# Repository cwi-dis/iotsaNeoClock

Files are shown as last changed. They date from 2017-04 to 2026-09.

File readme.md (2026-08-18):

# iotsaNeoClock - an internet-connected clock




A clock comprised of 60 NeoPixel LEDs. Shows the time, but can also show programmable patterns (as alerts) and temporal information (such as expected rainfall for the coming hour). Schematics and building instructions included.

Home page is <https://github.com/cwi-dis/iotsaNeoClock>.
This software is licensed under the [MIT license](LICENSE.txt) by the   CWI DIS group, <http://www.dis.cwi.nl>.

## Software requirements

* Arduino IDE, v1.6 or later.
* The iotsa framework, download from <https://github.com/cwi-dis/iotsa>.
* The new LiquidCrystal library, download from <https://bitbucket.org/fmalpartida/new-liquidcrystal>.
* The [Adafruit NeoPixel library](https://github.com/adafruit/Adafruit_NeoPixel).

## Hardware requirements

* a iotsa board (or another esp8266-based board).
* A strip of 60 NeoPixels.
* Optionally an LDR to auto-adjust the clock brightness.

## Hardware construction

Construction of the iotsa board is very simple: the NeoPixel strip _data in_ should be connected to _GPIO 14_ and _power_ and _ground_ should be connected to _5V_ and _GND_, respectively.

If you want light adaptation you also connect an LDR (light dependent resistor) between _AIN_ and _3V3_ and a resistor of around 10Kohm between _AIN_ and _GND_.

At this point you can test that things work (but you have to mentally group your 60 NeoPixels into 12 groups of 5, with the very first LED being at the top of the clock, and the last LED being the innermost at the 11 o'clock position).

Now you need to cut your NeoPixels into 12 groups of 5, and somehow affix them to a frame. There is a template in [extras/pixel-layout.pdf](extras/pixel-layout.pdf) to help you get things spaced correctly. The _data in_ of the 12 o'clock 5-pixel strip goes to the iotsa board. The _data out_ of the 12 o'clock 5 pixel strip goes to the _data in_ of the 1 o'clock 5 pixel strip. And so forth. The _data out_ of the 11 o'clock strip is not connected. All the _power_ are connected together (and to _5V_) and all the _ground_ are connected together (and to _GND_), how you do this does not matter. You probably want to tape or glue your wires to the template.

I bought a 5 euro clock with a glass front, ripped all the internals out and glued the NeoPixels to the template, then glued the template to what was left of the clock. Finally I put semi-opaque paper on the inside of the glass and put the clock together again.

If you have the LDR you want to somehow position it so that it catches the incident light on the clock (but not the light from the clock), and that it is not too ugly.

## Building the software

You need to define (or `#undef`) `WITH_BRIGHTNESS` depending on whether you want to be able to change the clock brightness over the net (and definitely if you have the LDR for auto-brightness).

If you want different colors for the hands your can adapt the `COLOR_SEC`, `COLOR_MIN` and `COLOR_HOUR` defines (in `iotsaNeoClockMod.h`). If you want different patterns to show the time you need to modify `IotsaNeoClockMod::updateClockFace()` in `iotsaNeoClockMod.cpp`.

## Operation

The first time the board boots it creates a Wifi network with a name similar to _config-iotsa1234_.  Connect a device to that network and visit <http://192.168.4.1>. Configure your device name (using the name _neoclock_ is suggested), WiFi name and password, and after reboot the iotsa board should connect to your network and be visible as <http://neoclock.local>.

### Configuration

Visit <http://neoclock.local/ntpconfig> to configure the NTP (Network Time Protocol) server to use (but the default _pool.ntp.org_ will usually work) and your timezone. After about half a minute the clock should have a fix and start displaying the right time. The time is also shown on the ntpconfig page and on the clock homepage.

You can change the brightness of the clock at <http://neoclock.local/brightness> (or, as JSON, at <http://neoclock.local/api/brightness>). You can either set a single brightness value, or set _Adapt to ambient light_ and set a minimum and maximum brightness.

You can set the LED rotation offset (the clock position where LED 0 actually sits -- needed on the first two clocks built, which have LED 0 at the 1 o'clock position) at <http://neoclock.local/neoclock> (or, as JSON, at <http://neoclock.local/api/neoclock>).

### Alerts

The clock can display alerts, which are sequences of patterns, there are sample patterns in [data/data](data/data).
Each line consists of 181 numbers: a duration (in milliseconds) and 60 R, G and B values for each of the pixels. Triggering an alert will simply show the lines in order.

Alerts share the device's generic `/upload` file store with arbitrary other files, so alert pattern files must be named `alert-<name>`, e.g. `alert-Red`. Upload via <http://neoclock.local/upload>, see what's available at <http://neoclock.local/alert> (or, as JSON, at <http://neoclock.local/api/neoclock>, which also reports the currently-playing alert, if any), then trigger with the name *without* the `alert-` prefix, e.g. <http://neoclock.local/alert?alert=Red>. Stop a running alert early with <http://neoclock.local/alert?stop=1>. The same trigger/stop can be done as JSON: `PUT /api/neoclock {"alert": "Red"}` / `{"alert": ""}`.

Alerts are intended to be shown programmatically when something interesting has happened, such as a doorbell being pushed, or a facebook mention, or whatever you can think of. [Igor](https://github.com/cwi-dis/iotsa) is a good way of connecting triggers to alerts.

### Status indicators

The clock can also display _status information_, which is intended to be longer-lived. Think of things like "the garden door is open" or "the temperature in the freezer is above -20 C". There are two types of status indicators, each with its own URL:

* <http://neoclock.local/status> -- the inner ring, used for _main status information_. All 12 LEDs show the same color and intensity.
* <http://neoclock.local/temporal> -- the outer ring, used for _temporal status information_, information for the coming hour. The LEDs all have the same color, but the intensity can vary. This can be used to get a quick visual indication of things like the expected rainfall in the coming hour.

Some example URLs to trigger status indicators:

```
http://neoclock.local/status?color=0x00ff00
```

Sets the inner ring to bright green.

```
http://neoclock.local/status?color=0x006600&timeout=60
```
Sets the inner ring to medium green for 60 seconds, then revert to normal.

```
http://neoclock.local/status?color=0&nextColor=0xff0000&timeout=300
```
Sets the inner ring to normal (unlit) for 5 minutes, then go to a very bright red. This can be used as a watchdog: by re-issuing this command within those 5 minutes the red will never show up. Unless the agent that is responsible for contacting the URL is too late.

```
http://neoclock.local/temporal?color=0xccffff&factors=1.0,0.0,0.0,0.5&timeout=300
```
Sets the outer ring with timed information. Where the minute hand is pointing is set to 100% lightish blue, 15 minutes into the future to that color with 50% intensity. After 5 minutes the outer ring will revert to normal.

### Automatic rain forecast (buienradar.nl)

Some NeoClocks have a built-in rain forecast feature: they periodically fetch the precipitation forecast for a configured location from [buienradar.nl](https://www.buienradar.nl) (Netherlands only) and use it to drive the outer ring automatically -- no external process needed to push `/temporal` updates.

If your clock has this feature, configure it at <http://neoclock.local/buienradar> (or, as JSON, at <http://neoclock.local/api/buienradar>): fill in your latitude and longitude -- the easiest way to find them is to right-click your location on Google Maps and copy the two numbers shown from the top of the menu that pops up (not "Copy link", which gives you something else entirely) -- and the outer ring will start showing the forecast for the coming hour automatically. There's also an _Enabled_ switch on that page, in case you ever want to turn the feature off.

If your clock doesn't have this feature, you can still get the same effect yourself: have some external process fetch a forecast periodically and push it to `/temporal`, as shown above.

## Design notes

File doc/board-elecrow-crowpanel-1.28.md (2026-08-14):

# Hardware reference: Elecrow CrowPanel ESP32 1.28" round display

Reference notes for the board being investigated for #4 ("multiple renderers"). Compiled from:

- The vendor's public repo, [Elecrow-RD/CrowPanel--ESP32-Display-1.28-R-inch-240240](https://github.com/Elecrow-RD/CrowPanel--ESP32-Display-1.28-R-inch-240240) (factory firmware source, other example sketches, Eagle schematic `CrowPanel ESP32 Display 1.28(R) Inch_V1.0_240507.sch`).
- Direct queries against a physical unit (`iotsa dfu info`, `espefuse summary`, USB descriptor inspection).

Confidence varies by item — noted per section. Where a claim comes only from the vendor's source/schematic and hasn't been independently exercised, it's marked accordingly.

**Board variants:** the single Eagle schematic appears to cover more than one Elecrow SKU sharing the same PCB, with some parts populated only on certain variants. Confirmed so far: the "extra flash" footprint (`U4`, below) really is silkscreened `U4` on the physical unit, matching the schematic — but that unit doesn't actually have it populated. Separately, this specific unit (the round-clock demo one) doesn't appear to have the rotary encoder populated or used either; Jack has a second variant of this board with a physical pushbutton + rotary encoder that most likely does populate and use it — and quite possibly `U4` too. Treat the encoder section below as "what the shared schematic supports," not as confirmed-present on this particular unit.

## MCU

- **ESP32-C3FH4** (schematic ref `U3`): single-core RISC-V @ 160MHz, 4MB flash embedded in-package (vendor `XMC`), WiFi + BT5 LE.
- Confirmed on the physical unit via `iotsa dfu info` / `espefuse summary`: silicon revision v0.4, 40MHz crystal, MAC `94:a9:90:54:e6:70`.
- Shipped with secure boot off, flash encryption off, no eFuse keys burned, download mode not locked out — open for reflashing.

## Power

- USB-C connector (`J1`, 16-pin) for power and programming.
- `RT9013-30PB` (`U6`): 5V → 3.3V LDO.
- `TP4054` (`U2`, DFN8): single-cell Li-ion/LiPo linear charger, with a `CHRG` status output.
- `B3`, a 1.0mm-pitch 4-pin battery connector (`BAT-1.0MM-W`) — only 2 of the 4 pins are used (`B+`/`B-`); the other two are tied straight to GND. This is almost certainly the 2-pin-looking JST-style connector you spotted — confirms the board is designed to take a LiPo cell and charge it over USB.
- Separately, a **CR927 coin-cell holder** (`B2`) diode-ORed (`D5`, dual-diode) onto the RTC's own supply rail (`VDD_RTC`) — an independent backup power source just for the BM8563 RTC chip and its 32.768kHz crystal, so timekeeping survives even with both USB and the main LiPo disconnected. Don't confuse this with the main LiPo connector — different purpose, different battery.

## Display + touch (round LCD module)

The GC9A01-driven 240×240 round IPS panel and its capacitive touch controller live on their own FPC module, connected to the mainboard via connector `J2`. Not independently verified — this is what the vendor's LovyanGFX init code claims, and the display visibly works, but the pin wiring itself hasn't been cross-checked any other way:

- SPI: `sclk`=GPIO6, `mosi`=GPIO7, `dc`=GPIO2, `cs`=GPIO10 (no `miso`, no dedicated hardware reset pin).
- Touch (CST816D): I2C, shared bus (`SDA`=GPIO4, `SCL`=GPIO5), `INT`=GPIO0. Never exercised in our testing (no touch events observed).
- Both **LCD reset** and **touch reset** are *not* direct GPIOs — both are routed through the IO expander (below). Same for **backlight enable**.

## IO expander — PI4IOE5V6408ZTAEX (`U1`)

I2C, address pin tied to GND (fixed address). This one chip fans out to several things that look at first glance like they'd be direct GPIOs:

| Expander pin | Net name | Drives |
|---|---|---|
| P0 | `MOTOR_P0` | Vibration motor (via transistor `Q3`) |
| P2 | `LED_P2` | LCD backlight enable (via MOSFET `Q1`, pulls `LEDK` low) |
| P3 | `TP_RESET` | Touch controller reset |
| P4 | `LCD_RESET` | LCD reset |
| P1, P5–P7 | — | Unused — factory firmware only configures P0–P4 as outputs |

The expander's `INT` pin exists on the chip but **is not wired to any ESP32-C3 GPIO** in this design — despite the schematic net being labeled `PI4-INT_IO3`, which looks like a GPIO3 reference but isn't connected to the MCU at all (verified from the net's wire list — it only touches the expander's own INT pin). The real GPIO3 net is separately named `BEEP_IO3` (see Buzzer, below) — an unfortunate naming collision in the schematic, not an actual shared pin. Practical upshot: expander state has to be polled over I2C, there's no interrupt-driven path.

This matches the factory firmware's own `set_pin_io()` calls in `setup()` exactly: pin 3 (`TP_RESET`) and pin 4 (`LCD_RESET`) are driven high first, and pin 2 (`LED_P2`, backlight) only after LVGL has finished initializing — avoids flashing garbage on screen before the UI is ready.

## RTC — BM8563EMA (`U7`)

I2C, shared bus, fixed address. 32.768kHz crystal (`Y1`). Backed up independently by the CR927 coin cell described above. Confirmed working — the factory firmware reads it once a minute and we saw the expected serial output.

## Rotary encoder + buttons

- Rotary encoder, part `E5A5-23-12-8` (`U5`): A=GPIO19, B=GPIO18, integrated pushbutton=GPIO8 (`ENCODER_A_PIN`/`ENCODER_B_PIN`/`SWITCH_PIN` in the factory source). Not independently exercised, and per Jack's physical inspection, likely **not populated on this particular unit** — see "Board variants" above. Probably populated and used on the sibling pushbutton+encoder variant instead.
- RESET (`K1`) and BOOT/download (`K2`, GPIO9) buttons — the standard pair for manual bootloader entry, though on this board it's normally unnecessary since the USB bridge chip auto-resets into the bootloader (see below).
- A third, side-mounted "custom" button (`K3`) → GPIO1 (`Custom_PIN`). Confirmed directly wired (not through the expander) from both the factory source and the standalone `Button.ino` vendor example.

## Buzzer

Passive piezo buzzer (`BP1`, part `BEEP_7525`), driven through transistor `Q2`, directly on GPIO3 (`tone()` in the factory firmware). Never triggered in our testing (alarm never fired).

## USB/serial bridge

`CH340X`/`CH340E` (`U9`) — an external WCH USB-to-UART bridge chip, **not** the ESP32-C3's own native USB-Serial-JTAG peripheral. RXD/TXD go to GPIO20/21; DTR/RTS are wired to RESET and BOOT(GPIO9) for automatic bootloader entry (no manual button-holding needed for `iotsa dfu`/`esptool`/`pio upload`).

Independently confirmed from the host side: macOS enumerates the connected device as USB VID `0x1A86` (WCH) — matches the schematic exactly.

**Build-flag consequence:** because this is an external UART bridge and not native USB-CDC, firmware for this board should *not* need `ARDUINO_USB_MODE`/`ARDUINO_USB_CDC_ON_BOOT`-style flags the way a native-USB ESP32-C3/S3 board would — `Serial` here is a plain UART, same as any classic Arduino board.

## Extra flash footprint — confirmed: `U4`, unpopulated on this unit

The schematic includes a **second, discrete 8MB SPI NOR flash chip**, `W25Q64JVXGIQ` (`U4`) — completely separate from the ESP32-C3's own embedded 4MB. It's fully wired in the schematic (all of `DO`/`DI`/`CLK`/`CS`/`WP`/`HOLD` connect to real nets), so this isn't a stub or a leftover — it's a real, designed-in part on an 8-pin package footprint.

No SRAM or PSRAM part appears anywhere in the design, so it was never a SRAM/PSRAM candidate. **Confirmed by physical inspection:** the unpopulated 2×4-pad footprint is silkscreened `U4`, matching this part exactly. Not populated on this unit — per the "Board variants" note above, likely populated on the sibling pushbutton+encoder variant instead, alongside the encoder.

One caveat that still applies even now it's confirmed unpopulated here: this wouldn't show up either way in `iotsa dfu info`'s flash-size report. That only detects the chip's *boot* flash (the embedded 4MB) via the standard bootloader flash-probe protocol — it has no visibility into a second chip sitting on what would be a separate, general-purpose SPI bus.

## Partition table (as shipped)

Read directly off the physical unit via `iotsa dfu info` — not present anywhere in the vendor's repo (no `partitions.csv` committed; this was purely an Arduino IDE build-time choice):

```
nvs        0x9000    0x5000   (20KB)
otadata    0xe000    0x2000   (8KB)
app0       0x10000   0x3c0000 (~3.75MB, single ota_0 slot — no ota_1)
spiffs     0x3d0000  0x20000  (128KB, littlefs)
coredump   0x3f0000  0x10000  (64KB)
```

Single OTA slot only — the factory firmware can be updated in place, but there's no second slot for A/B rollback the way `iotsa`'s own OTA mechanism expects. Whatever partition scheme we pick for an iotsa-based build on this board will need real `ota_0`+`ota_1` slots, and given how much of the 4MB the factory image already claims, actual binary size should be measured early rather than assumed to fit.

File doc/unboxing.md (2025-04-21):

# NeoClock Manual

## Unpacking and connecting

Insert the power supply (5 volt, tip positive) into the little board at the back of the clock and connect to a power outlet.

The clock should show short green hour hand, a long yellow minute hand, a moving white second indicator and a yellow or pink ring.

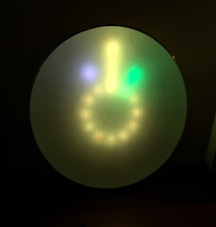
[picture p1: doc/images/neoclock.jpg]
Image of new NeoClock
> 

## Connecting to your WiFi

With the yellow or pink ring the NeoClock tells you that it does not know your WiFi. It will create its own WiFi network, with a name like _config-neoclock_ or _config-iotsa12345_ or something similar.

Connect to that WiFi network with a telephone, laptop or computer.

Open _Safari_ or _Chrome_ or another browser, and in the address bar type

```
http://192.168.4.1
```

This should show you the following window:

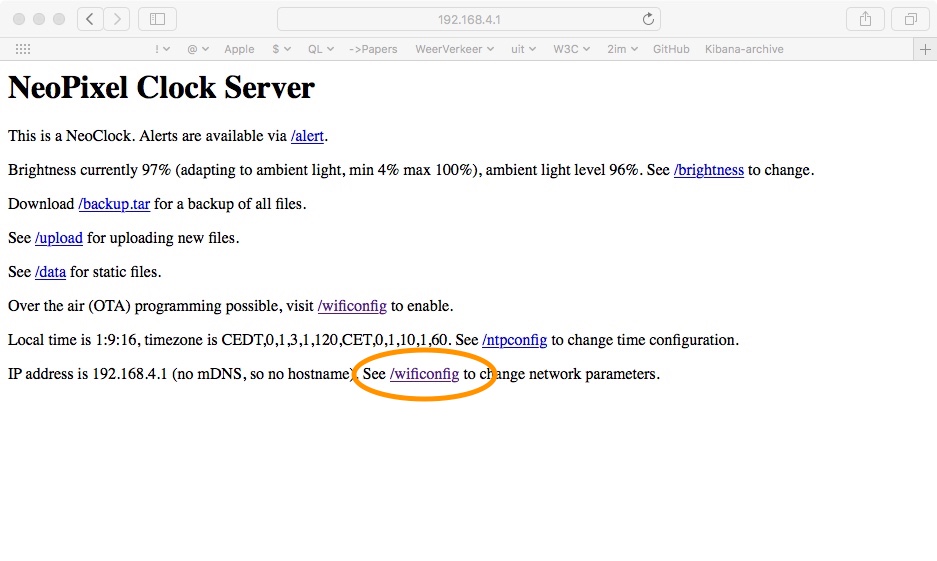
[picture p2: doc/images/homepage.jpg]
neoclock homepage screenshot
> 

Click the _/wificonfig_ link to go to the page where you can tell the NeoClock about your WiFi network:

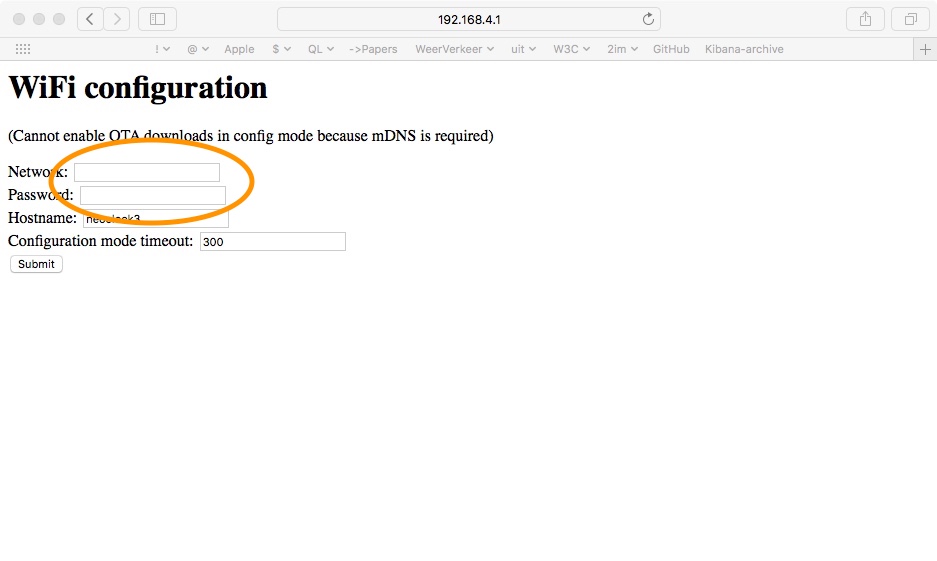
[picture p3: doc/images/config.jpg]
neoclock wificonfig screenshot
> 

Fill in the _Network_ and _Password_ fields with your WiFi name and WiFi password. 

Remember the name of your NeoClock, in the _Hostname_ field. (In this example it is _neoclock3_).

If you really want you can also give your clock a different name, but use only letters, digits and hyphen, no spaces or other characters. 

Press _Submit_.

The NeoClock will restart, and after a while should start showing a time (possibly wrong, because it does not know yet which timezone you are in), without the yellow center ring.

Connect your telephone (laptop, PC) back to your normal WiFi network.

## Configuring timezone

When both the NeoClock and your phone (laptop, computer) are connected to your WiFi network you can set it to the correct timezone by opening a browser and typing the following URL in the address bar (with the example _neoclock3_ replaced by the name you remembered above):

```
http://neoclock3.local
```

This will show you the _NeoPixel Clock Server_ page from above again. This time, select the _/ntpconfig_ link to bring you to the time configuration page:

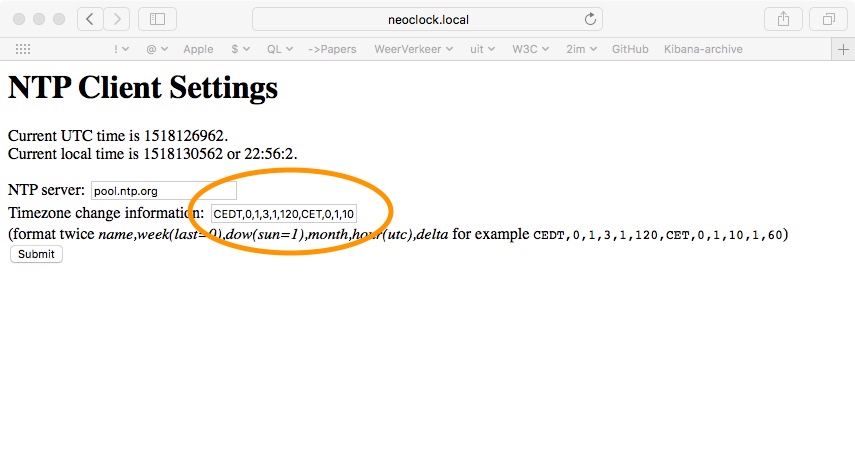
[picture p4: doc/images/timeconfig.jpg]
neoclock time config screenshot
> 

The format of the _Timezone change information_ configuration is rather complicated, but for continental Europe you can simply copy the example text 

```
CEDT,0,1,3,1,120,CET,0,1,10,1,60
```

and press _Submit_. 

> The format for the timezone string is called "posix TZ database". You can try looking up your location in <https://github.com/nayarsystems/posix_tz_db/blob/master/zones.csv>.

Your clock should now show the correct time.

## Clock brightness

You can change the brightness of the clock, and you can make it adapt to available light (so it does not blind you at night but you can still see it during the day).

> Note that adapting the brightness only works if your NeoClock has a little light sensor, probably somewhere near the top. Otherwise you can still set a brightness but it will not change.

Visit the clock homepage, and select the _/brightness_ page:

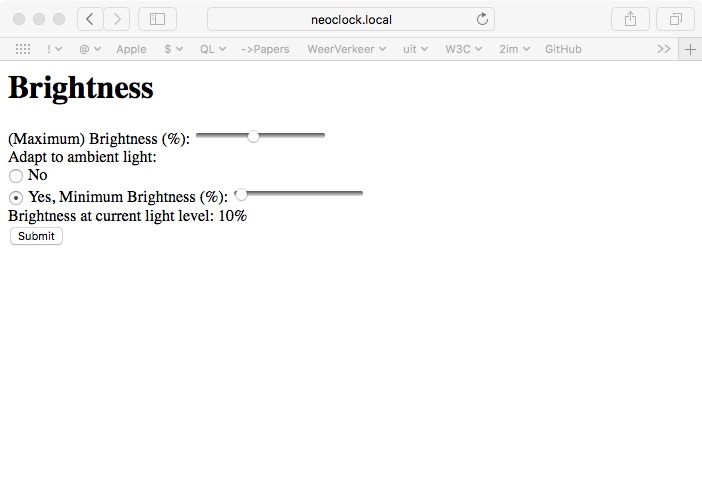
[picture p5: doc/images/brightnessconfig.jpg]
neoclock brightness config page
> 

Use the sliders to select maximum and minimum brightness, and select _Yes_ for adaptation. Press _Submit_.

You can test the brightness by covering the light sensor with something (or shining a light at it).

## More

Your NeoClock can do more things, like showing you alerts or showing things like rain prediction, but for these you need an additional local _Igor_ server. Or you can reprogram it yourself to show the time differently.

Visit <https://github.com/cwi-dis/iotsaNeoClock> and <https://github.com/cwi-dis/igor> if you are interested in this.

## Troubleshooting

If your NeoClock cannot find your WiFi network (for example because you mistyped the password) it will show an orange ring. After a few minutes it will show the yellow or pink ring again, and you can try connecting to the _config-neoclock3_ network again to reprogram it.

It will go into a sequence of trying to connect to the programmed network and its _config_ network every few minutes until everything is right.

There are a few other colors the ring can take:

- _orange_ trying to connect to your Wifi. Will go off (or turn to pink or yellow) after a couple of seconds.
- _red_ factory reset. Should not happen, remove power and hope it goes away.
- _blue_ reprogram. Should not happen, and should fix itself. If the NeoClock does not go back to normal in a few minutes: remove power and hope it goes away.

In case of other problems: contact <Jack.Jansen@cwi.nl> and he will try to help. If there are any lights on: a picture may help. If the are any moving lights on: a movie may help.

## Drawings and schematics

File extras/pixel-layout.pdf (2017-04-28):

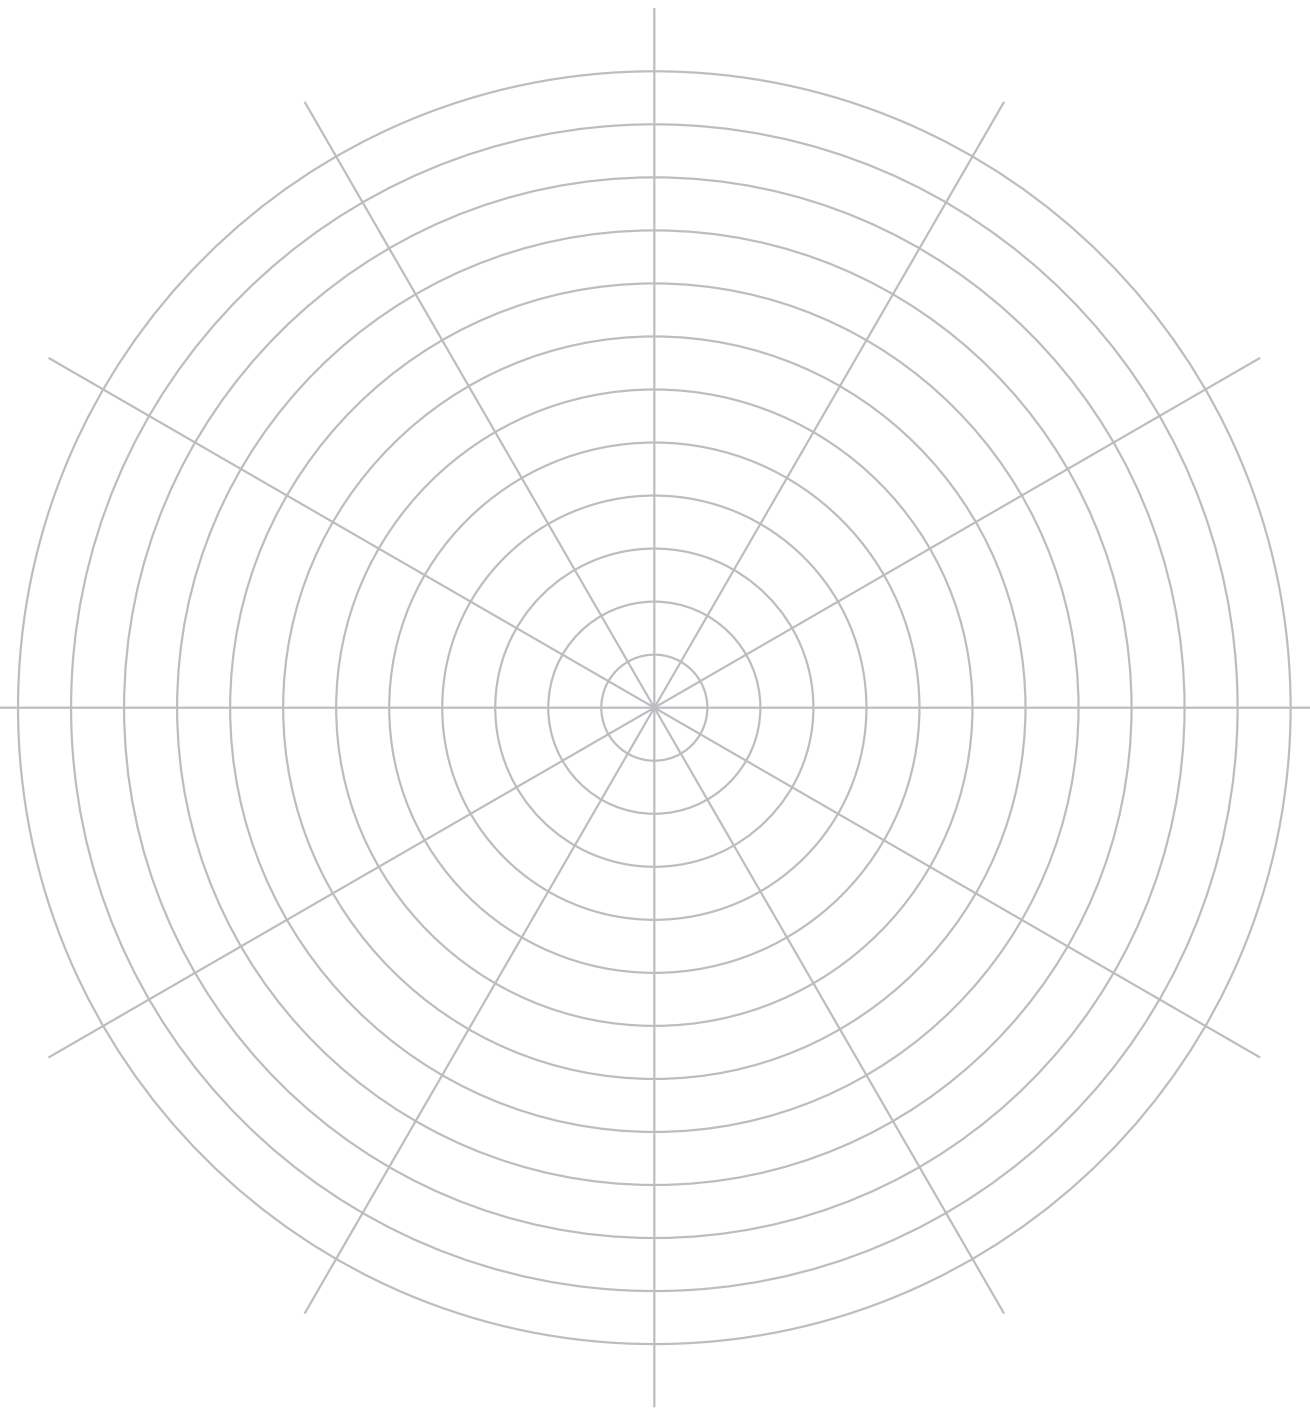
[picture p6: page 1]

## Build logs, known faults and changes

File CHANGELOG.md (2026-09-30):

# Changelog

All notable changes to this project will be documented in this file.

The format is based on [Keep a Changelog](https://keepachangelog.com/en/1.0.0/),
and this project adheres to [Semantic Versioning](https://semver.org/spec/v2.0.0.html).

## [Unreleased]

### Added

- Automatic rain forecast (buienradar.nl) driving the outer status ring, on clocks that have it enabled (#7)
- Identify command: two white flashes on the inner ring (cwi-dis/iotsa#133)

### Changed

- Migrated to iotsa v3 API (`IotsaModule` base class, `lateSetup()`, `webHandler()`, bare `api.setup()` paths) (cwi-dis/iotsa#199)
- `platformio.ini` now uses vendored `iotsa-board-*.ini` for board definitions instead of hand-copied board sections (cwi-dis/iotsa#224); esp8266 env renamed `nodemcuv2` → `iotsa_v4`
- esp8266: dropped the `4m3m` flash layout for the nodemcuv2 default (`4m1m`) — restores OTA headroom (the clock only needs ~15KB of LittleFS)
- esp32c3 (crowpanel): now built with `-DESP32C3`, which was previously missing
- Status colour now read via `iotsaStatus.statusColor()` (was `iotsaConfig.getStatusColor()`, moved in cwi-dis/iotsa#243)
- Rain ring uses igor's brighter teal colour and level-based scaling again (#11)
- Hour hand now overlays the minute hand instead of blending with it (#11)

### Removed

- `IotsaStatusInterface`/`application.status` (removed upstream in cwi-dis/iotsa#176) -- `render()` already polled `iotsaStatus.statusColor()` every `loop()`, so the push-based `showStatus()` callback was redundant. No behavior change: the inner ring still shows the same status colour, uniformly across all 12 LEDs, overridden by the alert mechanism when one is playing (cwi-dis/iotsaNeoClock#9)

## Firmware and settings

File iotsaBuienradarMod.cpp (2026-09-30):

#include "iotsaBuienradarMod.h"
#include "iotsaConfigFile.h"

// buienradar.nl's raintext endpoint: 24 lines of "LLL|HH:MM", one per 5-minute
// step covering the next 2 hours. We only need the first 12 (the next hour) --
// that's all setTemporalStatus()'s 12-segment ring can show. LLL is a
// logarithmic rain-intensity level (mm/h = 10^((LLL-109)/32), per buienradar's
// docs); we map the level itself, not mm/h, onto the ring -- see
// BUIENRADAR_LEVEL_OFF/_FULL.
//
// Note the trailing slash and the 2-decimal-place lat/lon below: the endpoint
// 302-redirects any request with more than 2 decimal places to a canonical
// URL truncated to its actual grid resolution, 0.01 degrees (~1.1km) --
// matching what igor's old pull.sh already truncated to. IotsaRequest doesn't
// follow redirects, so requesting more precision than that fails outright.
#define BUIENRADAR_URL "https://gadgets.buienradar.nl/data/raintext/"

// IotsaConfigFileLoad/Save's config files are one "name=value" per line, with
// '\n' as the record separator -- a multi-line PEM stored verbatim gets cut
// down to just its first line on save (silently corrupting it, since the
// remaining lines are then misread as further name=value entries that don't
// match anything). So the root CA is escaped to a single line for storage.
// Workaround for cwi-dis/iotsa#197; remove once that's fixed -- tracked in
// cwi-dis/iotsaNeoClock#8.
static String escapeNewlines(const String &s) {
  String r = s;
  r.replace("\n", "\\n");
  return r;
}

static String unescapeNewlines(const String &s) {
  String r = s;
  r.replace("\\n", "\n");
  return r;
}

void IotsaBuienradarMod::poll() {
  char query[32];
  snprintf(query, sizeof(query), "lat=%.2f&lon=%.2f", latitude, longitude);
  IFDEBUG {
    IotsaSerial.print("IotsaBuienradarMod: GET ");
    IotsaSerial.print(BUIENRADAR_URL);
    IotsaSerial.print("?");
    IotsaSerial.println(query);
    IotsaSerial.print("IotsaBuienradarMod: free heap before request: ");
    IotsaSerial.println(ESP.getFreeHeap());
  }
  String body;
  bool ok = req.send(query, &body);
  IFDEBUG {
    IotsaSerial.print("IotsaBuienradarMod: free heap after request: ");
    IotsaSerial.println(ESP.getFreeHeap());
  }
  if (!ok) {
    IFDEBUG IotsaSerial.println("IotsaBuienradarMod: request failed");
    return;
  }
  float factors[12];
  int nFactors = 0;
  int lineStart = 0;
  while (nFactors < 12 && lineStart < (int)body.length()) {
    int lineEnd = body.indexOf('\n', lineStart);
    if (lineEnd < 0) lineEnd = body.length();
    int barIdx = body.indexOf('|', lineStart);
    if (barIdx > 0 && barIdx < lineEnd) {
      int level = body.substring(lineStart, barIdx).toInt();
      // Clamping to exactly 0 matters: any factor > 0 trips combineRGB()'s
      // round-up-to-1 floor and shows faint dots, including for level 0
      // (buienradar's explicit "no rain").
      float factor = (float)(level - BUIENRADAR_LEVEL_OFF) / (BUIENRADAR_LEVEL_FULL - BUIENRADAR_LEVEL_OFF);
      if (factor < 0.0) factor = 0.0;
      if (factor > 1.0) factor = 1.0;
      factors[nFactors++] = factor;
    }
    lineStart = lineEnd + 1;
  }
  if (nFactors < 12) {
    IFDEBUG IotsaSerial.println("IotsaBuienradarMod: short/unparseable response, ignoring");
    return;
  }
  float maxFactor = 0;
  for (int i = 0; i < 12; i++) if (factors[i] > maxFactor) maxFactor = factors[i];
  IFDEBUG {
    IotsaSerial.print("IotsaBuienradarMod: OK, max factor ");
    IotsaSerial.print(maxFactor);
    IotsaSerial.println(maxFactor > 0 ? " (rain expected)" : " (no rain expected)");
  }
  neoClockMod.setTemporalStatus(COLOR_RAIN, factors, BUIENRADAR_STATUS_TIMEOUT_SECS);
}

void IotsaBuienradarMod::loop() {
  if (!enabled) return;
  if (latitude == 0.0 && longitude == 0.0) return; // not configured yet
  if (WiFi.status() != WL_CONNECTED) return;
  if (millis() < nextPollTime) return;
  nextPollTime = millis() + BUIENRADAR_POLL_INTERVAL_MS;
  poll();
}

void IotsaBuienradarMod::webHandler() {
  bool anyChanged = false;
  if (api.webService->server->hasArg("enabled")) {
    String e = api.webService->server->arg("enabled");
    bool ne = (e == "yes" || e == "true" || e.toInt() > 0);
    if (ne != enabled) { enabled = ne; anyChanged = true; }
  }
  if (api.webService->server->hasArg("latitude")) {
    float v = api.webService->server->arg("latitude").toFloat();
    if (v != latitude) { latitude = v; anyChanged = true; }
  }
  if (api.webService->server->hasArg("longitude")) {
    float v = api.webService->server->arg("longitude").toFloat();
    if (v != longitude) { longitude = v; anyChanged = true; }
  }
  if (api.webService->server->hasArg("rootCA")) {
    String v;
    IotsaBaseModule::percentDecode(api.webService->server->arg("rootCA"), v);
    if (v != req.sslInfo) { req.sslInfo = v; anyChanged = true; }
  }
  if (anyChanged) {
    configSave();
    nextPollTime = 0; // re-poll promptly with the new settings
  }

  String message = "<html><head><title>Buienradar rain forecast</title></head><body><h1>Buienradar rain forecast</h1><form method='get'>";
  message += "Enabled:<br><input name='enabled' type='radio' value='yes'";
  if (enabled) message += " checked";
  message += "> Yes<br><input name='enabled' type='radio' value='no'";
  if (!enabled) message += " checked";
  message += "> No <i>(kill switch, in case the live fetch misbehaves)</i><br>\n";
  message += "Latitude: <input name='latitude' value='" + String(latitude, 6) + "'><br>\n";
  message += "Longitude: <input name='longitude' value='" + String(longitude, 6) + "'><br>\n";
  message += "<p>Find your coordinates by right-clicking your location on <a href='https://maps.google.com' target='_blank'>Google Maps</a> and copying the two numbers shown.</p>\n";
  message += "Root CA certificate <i>(advanced -- only change if buienradar.nl's certificate issuer changes)</i>:<br>\n";
  message += "<textarea name='rootCA' rows='10' cols='70'>" + req.sslInfo + "</textarea><br>\n";
  message += "<input type='submit'></form></body></html>";
  api.webService->server->send(200, "text/html", message);
}

bool IotsaBuienradarMod::getHandler(const char *path, JsonObject& reply) {
  reply["enabled"] = enabled;
  reply["latitude"] = latitude;
  reply["longitude"] = longitude;
  return true;
}

bool IotsaBuienradarMod::putHandler(const char *path, const JsonVariant& request, JsonObject& reply) {
  bool anyChanged = false;
  JsonObject reqObj = request.as<JsonObject>();
  if (getFromRequest<bool, bool>(reqObj, "enabled", enabled)) anyChanged = true;
  if (getFromRequest<float, float>(reqObj, "latitude", latitude)) anyChanged = true;
  if (getFromRequest<float, float>(reqObj, "longitude", longitude)) anyChanged = true;
  if (anyChanged) {
    configSave();
    nextPollTime = 0;
  }
  return anyChanged;
}

void IotsaBuienradarMod::setup() {
  configLoad();
}

void IotsaBuienradarMod::lateSetup() {
  name = "buienradar";
  api.setup("buienradar", true, true);
}
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

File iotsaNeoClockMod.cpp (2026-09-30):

#include "iotsaNeoClockMod.h"
#include "iotsaConfigFile.h"
#include "iotsaRunmode.h"

#define IFDEBUGX if(0)

extern "C" {
  int _gettimeofday_r(struct _reent* unused, struct timeval *tp, void *tzp);
}

//
// Helper function - combine r/g/b values into rgb with clamping and checking
//
uint32_t IotsaNeoClockMod::combineRGB(uint32_t oldRGB, float factor, int red, int green, int blue) {
  red = (int)(red*factor) + int(red > 0 && factor > 0);
  green = (int)(green*factor) + int(green > 0 && factor > 0);
  blue = (int)(blue*factor) + int(blue > 0 && factor > 0);
  red += (oldRGB >> 16) & 0xff;
  green += (oldRGB >> 8) & 0xff;
  blue += oldRGB & 0xff;
  if (red > 255) red = 255;
  if (green > 255) green = 255;
  if (blue > 255) blue = 255;
  if (red < 0) red = 0;
  if (green < 0) green = 0;
  if (blue < 0) blue = 0;
  return (red << 16) | (green << 8) | blue;
}

//
// Helper function - blend color into a buffer pixel
//
void IotsaNeoClockMod::blendPixel(uint32_t colors[NUM_LEDS], int idx, float factor, uint32_t rgb, float brightness) {
  int red = (rgb >> 16) & 0xff;
  int green = (rgb >> 8) & 0xff;
  int blue = rgb & 0xff;
  factor = factor * brightness;
  colors[idx] = combineRGB(colors[idx], factor, red, green, blue);
}

// Saturating per-channel add of two already-scaled colors (no factor, so no
// combineRGB() round-up floor).
static uint32_t addRGB(uint32_t a, uint32_t b) {
  uint32_t rv = 0;
  for (int shift=0; shift<24; shift+=8) {
    uint32_t c = ((a >> shift) & 0xff) + ((b >> shift) & 0xff);
    rv |= (c > 255 ? 255 : c) << shift;
  }
  return rv;
}

//
// Data provider: clock hands (seconds/minutes/hours).
//
void IotsaNeoClockMod::updateClockFace(uint32_t colors[NUM_LEDS], const ClockTime &time, int ledRotationOffset, float brightness) {
  // Seconds
  {
    // Transition window (width W on each side of a second boundary): a full
    // 0..1 handoff between the outgoing and incoming LED, evaluated so that
    // both sides of a boundary agree exactly at the boundary itself (0.5/0.5)
    // -- this must stay continuous across the frac=1->0 second rollover, or
    // the "self" LED's brightness visibly jumps instead of flowing. W=0.5
    // spans the whole second, so there's no held-still plateau at 1.0 --
    // a narrower W reads as "static, then a quick flick" since most of the
    // second would then pass with nothing changing.
    const float W = 0.5;
    float frac = time.frac;
    float valBefore = 0, valAfter = 0, valSelf;
    if (frac < W) {
      float s = (frac + W) / (2*W);
      valSelf = s;
      valBefore = 1 - s;
    } else if (frac > 1-W) {
      float s = (frac - (1-W)) / (2*W);
      valAfter = s;
      valSelf = 1 - s;
    } else {
      valSelf = 1.0;
    }
    IFDEBUGX { IotsaSerial.printf("seconds=%d, before=%f, self=%f, after=%f", time.seconds, valBefore, valSelf, valAfter); IotsaSerial.println(); }

    int ledSelf = (FIRST_SEC_LED+time.seconds - ledRotationOffset*STRIDE_HOUR_LEDS + NUM_LEDS) % NUM_LEDS;
    int ledBefore = (ledSelf + NUM_LEDS-1) % NUM_LEDS;
    int ledAfter = (ledSelf + 1) % NUM_LEDS;
    if (valBefore) {
      blendPixel(colors, ledBefore, valBefore, COLOR_SEC, brightness);
    }
    if (valSelf) {
      blendPixel(colors, ledSelf, valSelf, COLOR_SEC, brightness);
    }
    if (valAfter) {
      blendPixel(colors, ledAfter, valAfter, COLOR_SEC, brightness);
    }
  }
  // Minute and hour hands are drawn into their own buffers so the (shorter)
  // hour hand can overlay the minute hand instead of blending with it (#11);
  // the combined hands are then added onto the frame like everything else.
  uint32_t hands[NUM_LEDS] = {0};
  uint32_t hourHand[NUM_LEDS] = {0};
  // Minutes
  {
    int minutes = time.minutes;
    int minMod5 = minutes % 5;
    minutes = minutes / 5;
    IFDEBUGX { IotsaSerial.printf("minutes=%d*5 + %d\n", minMod5, minutes);}
    int firstLed = FIRST_MIN_LED + ((minutes-ledRotationOffset+12)%12)*STRIDE_MIN_LEDS;
    if (firstLed >= NUM_LEDS) firstLed -= NUM_LEDS;

    // Set all the pixels corresponding to the minute hand
    for (int i=firstLed; i<firstLed+NUM_MIN_LEDS; i++) {
      blendPixel(hands, i, 1.0, COLOR_MIN, brightness);
    }
    // And set the one corresponding to the current minute again, to highlight it
    blendPixel(hands, firstLed+minMod5, 1.0, COLOR_MIN, brightness);
  }
  // Hours
  {
    int hours = time.hours;
    IFDEBUGX { IotsaSerial.print("hours="); IotsaSerial.println(hours); }
    int firstLed = FIRST_HOUR_LED + ((hours-ledRotationOffset+12)%12)*STRIDE_HOUR_LEDS;
    int extraLed = 0;
    // Determine which segment to show the hour hand (depending on whether where
    // at <30 minutes past the hour or >30 minutes past) and
    // which of the three hour-hand leds to highlight
    float frac = time.minutes/60.0;
    if (frac < 0.1666) {
      extraLed = 0;
    } else
    if (frac < 0.3333) {
      extraLed = 1;
    } else
    if (frac < 0.5) {
      extraLed = 2;
    } else
    if (frac < 0.6666) {
      firstLed += STRIDE_HOUR_LEDS;
      extraLed = 0;
    } else
    if (frac < 0.8333) {
      firstLed += STRIDE_HOUR_LEDS;
      extraLed = 1;
    } else {
      firstLed += STRIDE_HOUR_LEDS;
      extraLed = 2;
    }

    // Light up the correct hour hand
    while (firstLed >= NUM_LEDS) firstLed -= NUM_LEDS;
    for (int i=firstLed; i<firstLed+NUM_HOUR_LEDS; i++) {
      blendPixel(hourHand, i, 1.0, COLOR_HOUR, brightness);
    }
    // And highlight the pixel corresponding to where in the half hour we are
    blendPixel(hourHand, firstLed+extraLed, 1.0, COLOR_HOUR, brightness);
  }
  for (int i=0; i<NUM_LEDS; i++) {
    if (hourHand[i]) hands[i] = hourHand[i];
    colors[i] = addRGB(colors[i], hands[i]);
  }
}

//
// Data provider: main status ring (inner ring, one uniform color)
//
void IotsaNeoClockMod::updateStatus(uint32_t colors[NUM_LEDS], const StatusState &state, float brightness) {
  if (state.color == 0) return;
  for(int i=STRIDE_HOUR_LEDS-1; i<NUM_LEDS; i+=STRIDE_HOUR_LEDS) {
    blendPixel(colors, i, 1.0, state.color, brightness);
  }
}

//
// Data provider: temporal status ring (outer ring, one color per 5-minute segment).
// ledRotationOffset must match updateClockFace's, or this ring ends up rotated
// relative to the clock hands (cwi-dis/iotsaNeoClock#2's underlying 5-year-old bug,
// on the two clocks that need a nonzero offset).
//
void IotsaNeoClockMod::updateTemporalStatus(uint32_t colors[NUM_LEDS], const TemporalStatusState &state, int ledRotationOffset, float brightness) {
  int idx = 0;
  for(int i=0; i<NUM_LEDS; i+=STRIDE_HOUR_LEDS) {
    int segment = (idx + ledRotationOffset) % 12;
    blendPixel(colors, i, 1.0, state.colors[segment], brightness);
    idx++;
  }
}
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

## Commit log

2017-04-28 Renaming things to prepare for git migration
    [NeoClock-Hardware-bb.fzz]
2018-01-28 Clamp minimum light level per color to 1 (so for example orange doesn't go to red in case of low light levels)
2018-03-15 Fix for mixup with where the first led is.
2020-04-16 Don't include esp32_https_server_compat
2020-12-28 Arduino action
2021-01-03 Build all iotsa products for at least nodemcuv2 and esp32thing
2021-01-03 Use board_build.ldscript
2021-01-03 Fixed to compile on esp32
2024-12-25 Use min_spiffs on esp32.
2025-04-21 Use milliseconds from corect time to determine fading of seconds, not millis() which is not in sync
2025-04-27 Updated arduino build job
2026-07-22 #149 bullet 2: refactor into standard module structure, fix rotation bug
    Splits the old single-file iotsaNeoClock.ino (everything in free
    functions + globals) into:
    - iotsaNeoClock.ino: near-empty, matches the smartmeter/Skeleton
    convention (Arduino IDE compat kept)
    - mainNeoClock.cpp: glue (module instantiation, setup/loop)
    - NeoClockDisplay.h / NeoPixelStripDisplay.h: thin hardware interface
    and its Adafruit_NeoPixel-backed implementation, so the rendering
    code doesn't talk to the strip library directly
    - iotsaNeoClockMod.h/.cpp: the compositing module (clock face, alert
    playback, main/temporal status rings), with the three data-transform
    pieces (updateClockFace/updateStatus/upd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
    [iotsaNeoClockMod.cpp, iotsaNeoClockMod.h]
2026-07-22 Reverse ledRotationOffset sign so it reads as the natural clock position
    Offset now equals the clock-face position where LED 0 physically sits
    (1 for the first two clocks built, at the 1 o'clock spot) instead of
    the wraparound value (11) the previous additive formula required.
    [iotsaNeoClockMod.cpp, iotsaNeoClockMod.h]
2026-07-22 #149 bullet 4: add REST API to IotsaNeoClockMod and IotsaBrightnessMod
    /api/neoclock exposes ledRotationOffset, /api/brightness exposes
    brightnessFactor/autoBrightness/minBrightnessFactor -- both mirror the
    existing web-form config, following the IotsaApiMod pattern used
    elsewhere (e.g. iotsaEstimote). Also simplified
    IotsaBrightnessMod::handler() from an args()-index scan to hasArg(),
    matching the modernized handler style used throughout this repo now.
2026-08-12 Use cmArduinoJWT fork instead of unmaintained ArduinoJWT
    Fixes cwi-dis/iotsa#184
2026-08-13 Replace fork --git-url installs with Library Manager references in Arduino CI
    cmArduinoJWT and esp32_idf5_https_server_compat are now published in the
    Arduino Library Manager, so the arduino-cli workflow no longer needs
    --git-url installs for them (esp32_idf5_https_server resolves
    transitively via esp32_idf5_https_server_compat's own depends=). iotsa
    itself is still installed via --git-url, pinned to the branch/ref under
    test.
    cwi-dis/iotsa#96
2026-08-13 arduino-cli: force a fresh library index before name-based lib installs
    The previous commit switched cmArduinoJWT and esp32_idf5_https_server_compat
    from --git-url installs to name-based Library Manager lookups. That exposed
    a latent bug in the "Cache Arduino CLI" step: its cache key hashes
    *_index.json in the repo working directory, which doesn't exist here, so
    the key is effectively static and a cache-hit silently restores whatever
    library_index.json was saved on the very first run -- forever, since
    arduino-cli only auto-downloads that index when it's completely absent,
    never when it's merely stale.
    Confirmed locally (with arduino-cli installed via brew): installing
    cmArduinoJWT against a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
2026-08-14 ci: bump GitHub Actions to current majors (checkout@v7, setup-python@v7, upload-artifact@v7, cache@v6)
    These were pinned to versions from 2020-2021 (checkout@v2, setup-python@v2 -
    both Node16, upload-artifact@v4, cache@v2), well past their supported
    window. Matches the versions already verified working in iotsa itself.
2026-08-14 #4: hardware reference for the Elecrow CrowPanel 1.28" round display
    Compiled from the vendor's public repo (factory firmware source, other
    example sketches, Eagle schematic) plus direct queries against the
    physical unit (iotsa dfu info, espefuse summary, USB descriptor).
2026-08-16 #4: add CrowPanel round-LCD renderer
    New NeoClockDisplay implementation (CrowPanelRoundDisplay) for the Elecrow
    CrowPanel ESP32-C3 1.28" round LCD, selected via WITH_ROUNDLCD_DISPLAY
    alongside the existing WITH_NEOPIXEL_DISPLAY NeoPixel backend. Draws a
    60-dot ring via LovyanGFX, diffing against the last-drawn frame so only
    changed dots are redrawn. PI4IOE5V6408 is a small driver for the board's
    I2C IO expander, which gates the LCD/touch reset lines and backlight.
    Adds a new crowpanel128 PlatformIO env (esp32-c3-devkitm-1, min_spiffs.csv
    partitions). Verified on the physical board: builds, flashes via a full
    image write (bootloader+partitions+app, since the vendor's factory
    partition table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
    [CrowPanelRoundDisplay.cpp, PI4IOE5V6408.cpp]
2026-08-16 #4: fix round-LCD dot layout to match the physical spoke wiring
    CrowPanelRoundDisplay::dotPosition() treated the 60 LEDs as a uniform
    60-position ring. The physical NeoClock is actually 12 radial 5-LED
    strips ("spokes"), one per clock-hour position, wired outer-to-inner
    within each strip (data-in end outermost, data-out end innermost) --
    see readme.md's construction notes. Fixed to place dots by spoke/radius
    instead of pure angle, so the second hand now steps inward along a
    spoke for 5 ticks before jumping out to the next spoke, matching the
    real NeoClock's look instead of sweeping smoothly around the circle.
    [CrowPanelRoundDisplay.cpp]
2026-08-17 #2: apply ledRotationOffset to the seconds and minutes hands too
    updateClockFace's hour block (and updateTemporalStatus, fixed earlier in
    bfd9a02) already compensated for ledRotationOffset, but the seconds and
    minutes hands never did -- true since the original FIRST_LED_AT_ONE_O_CLOCK
    compile-time flag, which only ever adjusted the hour hand. Since all hands
    share the same physical 60-LED chain (12 spokes of 5), a nonzero offset
    needs to shift all of them equally or they end up visibly misaligned
    relative to each other. Confirmed live on neoclock (ledRotationOffset=1):
    before this fix the second hand rendered one spoke (30 degrees) further
    around than the hour hand/status ring.
    Co-Authored-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
    [iotsaNeoClockMod.cpp]
2026-08-18 Fix temporal-status ring rotation sign and anchor it one segment ahead of the minute hand
    The outer forecast ring applied ledRotationOffset with the opposite sign
    from the hour/minute hands (3b7b7a0), invisible at the default offset=0
    but off by 2x the offset otherwise -- confirmed on lcdclock (offset=3)
    via a synthetic A/B test against neoclock. Also shifts factors[0] to
    display one segment ahead of the current minute rather than at it, since
    that reads more naturally for a "next hour" forecast.
    [iotsaNeoClockMod.cpp]
2026-08-18 Gamma-correct round-LCD colors so dim values survive RGB565 truncation
    color565() truncates each channel to 5/6/5 bits, so raw values below ~8
    round straight to zero -- unlike a WS2812's 8-bit PWM, which stays
    visibly nonzero much further down. The temporal-status comet trail's
    dim tail (e.g. factor=0.02) was landing below that floor and vanishing
    on lcdclock while remaining visible on neoclock for the same request.
    [CrowPanelRoundDisplay.cpp]
2026-08-18 #3: fix discontinuous seconds-hand transition at second boundaries
    valBefore/valAfter were each computed from the current second's own
    frac in isolation, capped at a 0.2 max blend, with no shared reference
    point between adjacent seconds. At the exact second boundary this made
    the "self" LED's brightness snap between 0.8 and 0.2 instead of
    flowing, since the outgoing second's tail-end blend and the incoming
    second's head-start blend didn't agree. Replaced with a single
    transition window, shared across the boundary, that does a full 0..1
    handoff and evaluates to the same 0.5/0.5 split from both sides.
    [iotsaNeoClockMod.cpp]
2026-08-18 #3: widen the seconds-hand transition to the full second, removing the hold plateau
    With the previous W=0.2, the transition only spanned 40% of each
    second; the LED then sat static at full brightness for the remaining
    60%, which read as "static, then a quick flick" rather than continuous
    motion even though the underlying formula was already boundary-
    continuous. W=0.5 spreads the flow across the whole second instead.
2026-08-18 #5: clean up the alert mechanism -- drop binary format, add a decent API
    - Drop the binary alert format entirely (read32bin(), currentAlertIsBinary,
    extras/alert2bin.py, data/data/inGreen.bin): it was never meaningfully
    smaller than the equivalent ascii pattern, and dropped the parsing code
    needed to support it. Ascii-only now.
    - Alert files shared iotsa's generic /data upload directory with arbitrary
    other files, and the listing naively showed everything under /data as if
    it were an alert. Alert files are now required to be named
    "alert-<name>", and only those are listed/triggerable -- also fixes a
    confirmed ESP32-only bug where the listing unconditionally stripped 6
    charact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
    [iotsaNeoClockMod.cpp, iotsaNeoClockMod.h]
2026-08-18 Fix combineRGB() applying its round-up-to-1 floor even when factor is 0
    The +1 floor (meant to keep a tiny nonzero blend factor from truncating
    to 0) was conditioned on the target channel value being >0, not on the
    factor itself being >0 -- so a factor of exactly 0.0 still nudged that
    channel to 1/255. Invisible on the NeoPixel strip's 8-bit PWM, but the
    round LCD's gamma correction (3f64125) deliberately amplifies near-zero
    values to survive RGB565 truncation, turning that stray 1 into a
    faintly visible dot. Found by visually inspecting a live temporal-status
    push where several supposedly-zero segments should have been fully dark.
    [iotsaNeoClockMod.cpp]
2026-08-18 #7: add automatic buienradar.nl rain forecast for the outer ring
    New IotsaBuienradarMod polls buienradar.nl for a configured lat/lon and
    drives IotsaNeoClockMod's outer ring directly via a new
    setTemporalStatus() method, instead of relying on an external process
    to push /temporal updates. Config (lat/lon, enabled switch, root CA)
    lives at /buienradar. Gated behind WITH_BUIENRADAR, enabled on the
    ESP32 envs only for now -- ESP8266 feasibility (BearSSL heap headroom)
    is unverified and left for later.
    Also fixes temporalStatusColorEndTime being set but never actually
    checked in render() -- the outer ring now genuinely clears on timeout,
    which the new module relies on to blank itself after a mi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
    [iotsaBuienradarMod.cpp, iotsaNeoClockMod.cpp, iotsaNeoClockMod.h]
2026-08-18 #7: enable buienradar rain forecast on ESP8266, drop unused esp32thing env
    ESP8266's IotsaRequest HTTPS path pins a certificate fingerprint rather
    than a root CA (see cwi-dis/iotsa#198's commit message for why), so
    iotsaBuienradarMod's sslInfo default/validation/label are now
    platform-conditional to match. Relies on iotsa#198's MFLN small-buffer
    fix -- without it this OOM-crashes the device (28KB free heap can't
    fit BearSSL's 16KB default receive buffer). Verified working against
    a real deployed nodemcuv2 clock once that fix was in place.
    Also drops esp32thing (env, CI matrix entries): never had any actual
    NeoClock hardware, was only ever used for early bring-up. crowpanel128
    takes its plac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
    [iotsaBuienradarMod.cpp]
2026-08-18 #7: unify ESP8266/ESP32 root-CA handling, delay first poll past boot
    Follows cwi-dis/iotsa#198's follow-up commit: ESP8266 now pins the
    issuing root CA like ESP32 (rather than the leaf certificate's
    fingerprint), so iotsaBuienradarMod no longer needs a platform split
    for sslInfo's default/label/validity check -- one PEM default for
    both.
    Also delay the module's first poll until a full interval after boot
    instead of firing immediately: an immediate poll can race NTP (CA
    verification needs a correctly-set clock to check validity dates,
    unlike the old fingerprint pinning) and fail once on "not yet valid";
    delaying also leaves a window to disable the feature via /buienradar
    before it ever makes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
    [iotsaBuienradarMod.cpp]
2026-08-23 Fix build-arduino CI: pass -DWITH_NEOPIXEL_DISPLAY/-DWITH_BUIENRADAR
    arduino-cli compile doesn't read platformio.ini, so the ESP8266 build was
    missing the defines that select the NeoPixel display and enable the rain
    forecast, and failed with "neoClockDisplay was not declared". crowpanel128
    (ESP32-C3) is left out of this workflow for now -- the Arduino toolchain
    can't compile iotsa itself for that chip, see cwi-dis/iotsa#200.
2026-08-29 Vendor iotsa board definitions; rework platformio.ini (cwi-dis/iotsa#224)
    - add iotsa-board-traits.ini + iotsa-board-defs.ini, vendored from cwi-dis/iotsa
    @ 9505640; platformio.ini now extra_configs's them instead of hand-rolled
    [esp8266]/[esp32c3] sections
    - [env:iotsa_v4] (was [env:nodemcuv2]) extends the iotsa_v4 board-def; drop the
    eagle.flash.4m3m.ld override -> nodemcuv2 default 4m1m, restoring ~2MB OTA
    headroom (the clock uses ~15KB of LittleFS)
    - [env:crowpanel128] extends iotsa's crowpanel128 board-def (external-USB C3
    trait): now builds with -DESP32C3, which was previously missing; drop the
    bespoke CH340 warning comment, iotsa models this board correctly now
    - local pat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
2026-08-30 Fix the bare Arduino build: default the display/feature flags in source
    The v3 migration split the old single .ino into mainNeoClock.cpp + modules,
    so WITH_NEOPIXEL_DISPLAY / WITH_BUIENRADAR now only arrive via platformio.ini
    build_flags (or a CI --build-property). A plain `git clone` + Arduino IDE
    build got neither, so mainNeoClock.cpp failed to compile (`neoClockDisplay`
    undeclared).
    Both flags are used only in mainNeoClock.cpp, so default them there when no
    build_flags are set:
    #if !defined(WITH_NEOPIXEL_DISPLAY) && !defined(WITH_ROUNDLCD_DISPLAY)
    #define WITH_NEOPIXEL_DISPLAY
    #endif
    #ifndef WITH_BUIENRADAR
    #define WITH_BUIENRADAR
    #endif
    A bare Arduino build is always the esp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
2026-08-31 board-defs: re-vendor from iotsa v3.0a2 (drop #226/#228 local patches)
    Re-vendor iotsa-board-defs.ini verbatim from iotsa v3.0a2. Two local
    patches are now upstream and gone from the vendored copy:
    - [crowpanel128] board_build.partitions = min_spiffs.csv (cwi-dis/iotsa#226),
    which also gains board_build.mcu / board_upload.flash_size upstream;
    - [lolin32] board = lolin32_lite (cwi-dis/iotsa#228).
    platformio.ini: drop the now-stale "the one marked local patch aside"
    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
2026-09-04 Rename iotsaConfig.getStatusColor() -> iotsaStatus.statusColor()
    cwi-dis/iotsa#243 moved the status-colour helper off IotsaConfig (it's a
    derived view of mode + wifi state, no persisted config involved) onto the
    IotsaStatus bus. render() called it twice per frame; now reads once into a
    local.
    Claude-Session: https://claude.ai/code/session_017NPviDGQHTQ9DxGH4ebYg8
2026-09-20 Drop IotsaStatusInterface/showStatus() (removed upstream in iotsa#176)
    render() already polls iotsaStatus.statusColor() every loop() call and
    overlays it onto the inner ring (all 12 LEDs, uniformly), so the push-based
    showStatus() callback was redundant -- the alert mechanism still overrides
    everything when active, unchanged. No behavior change.
    Fixes cwi-dis/iotsaNeoClock#9 (step 1). Step 2 (a from-scratch overlay
    redesign) doesn't apply: render()'s existing precedence already matches
    what that step asked for.
    [iotsaNeoClockMod.cpp, iotsaNeoClockMod.h]
2026-09-24 Pin LovyanGFX to 1.2.29: 1.2.30 overflows the crowpanel128 app partition
    LovyanGFX 1.2.30 compiles the library as one source file, and unused
    panel/touch drivers and data (incl. a 227 KB FPGA bitstream) are no
    longer dropped at link time: +560 KB, image no longer fits min_spiffs.csv.
    See #10, blocked on lovyan03/LovyanGFX#940.
2026-09-30 Rain ring: restore igor's colour and level-based scaling (#11)
    The native buienradar module used pure blue 0x000055 with a factor
    linear in mm/h (5 mm/h = full), which makes ordinary light rain nearly
    invisible: 0.3 mm/h came out as blue 6. Go back to what igor's neoclock
    plugin did: teal 0x206060, factor linear in buienradar's logarithmic
    level (level*0.01-0.4, clamped), so 0.3 mm/h shows at about half
    brightness. Clamping to exactly 0 keeps the "no faint dots when there
    is no rain" fix. Not yet checked visually (no rain forecast today).
    [iotsaBuienradarMod.cpp]
2026-09-30 Overlay the hour hand on the minute hand instead of blending (#11)
    Minute and hour hands are drawn into their own buffers; hour-hand pixels
    replace minute-hand pixels, and the combined hands are then added onto
    the frame (status rings, second hand) exactly as before, via a plain
    saturating add so the hands don't pick up combineRGB()'s round-up floor.
    Checked on both clocks at midnight, where the hands overlap.
    [iotsaNeoClockMod.cpp]
2026-10-05 Re-vendor iotsa board definitions; drop redundant min_spiffs.csv lines
    Refreshes iotsa-board-traits.ini / iotsa-board-defs.ini from iotsa
    develop (last vendored 2026-08-31). Picks up:
    - espressif32 platform pinned to 7.1.3 (cwi-dis/iotsa#269)
    - board_build.filesystem = littlefs, so `pio run -t uploadfs` builds an
    image the firmware can mount (cwi-dis/iotsa#269)
    - min_spiffs.csv as the default partition layout for all 4MB ESP32
    boards (cwi-dis/iotsa#245), making local board_build.partitions =
    min_spiffs.csv lines redundant -- removed where present
    - the NimBLE host-task stack flag for all ESP32 builds (cwi-dis/iotsa#127)
    Resolved config checked before/after with `pio project config`: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
2026-10-06 Adapt to iotsa's standard modules and per-application authenticator
    Re-vendor iotsa-board-traits.ini / iotsa-board-defs.ini from iotsa
    develop (status LED defines: IOTSA_PIN_LED, IOTSA_LED_NEOPIXEL,
    IOTSA_LED_ACTIVE_LOW).
    - Drop the IotsaWifiMod/IotsaOtaMod declarations: iotsa now creates the
    WiFi and OTA modules automatically (cwi-dis/iotsa#85).
    - Module constructors no longer take an authenticator: modules use the
    application's one (cwi-dis/iotsa#284).
2026-10-10 crowpanel128: LovyanGFX ^1.2.32 instead of the 1.2.29 pin (#10)
    lovyan03/LovyanGFX#940 is fixed in 1.2.32: the bloat came from the old
    RISC-V assembler (esp-2021r2) emitting .rela.eh_frame relocations out
    of order, which made --gc-sections keep everything in 1.2.30's single
    translation unit. 1.2.32 splits the library into a few translation
    units again. With iotsa 3.0a11, firmware.bin is 1,575,552 bytes vs
    1,558,208 with 1.2.29 (+17 KB); tested on lcdclock.
    Fixes #10.
2026-10-23 Request contexts and named rights (cwi-dis/iotsa#183)
    Follows iotsa's conversion (cwi-dis/iotsa#183, #296) and its rights
    (https://github.com/cwi-dis/iotsa/issues/183#issuecomment-6368033789):
    - /alert, /status and /temporal are triggers, with the same URLs and
    arguments; the alert list moved to the /neoclock page (a button per
    alert). PUT /api/neoclock also takes status and temporal.
    - Rights: alerts, the status rings and the brightness are open;
    ledRotationOffset and the rain forecast need "config" (reading the
    forecast's coordinates too: they give away where the clock hangs);
    adapting the brightness to the room needs "lighttuning".
    - Brightness on the page is a factor (0.0 to 1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
2026-10-23 Temporal ring: gamma, so a factor looks like that intensity; full rain at 12 mm/h (#11)
    LEDs are linear and eyes aren't: rain factors of 0.86 and 0.37 looked
    much the same. The temporal ring now shows factor^temporalGamma, a
    setting on /neoclock (default 2.2, right "lighttuning"); a change
    redraws the ring at once. Buienradar's full-brightness level is 144
    (about 12 mm/h) instead of 140 (about 9 mm/h).
2026-10-25 iotsa 3.0a15: log macros, board files
    Log lines through iotsaLog.h (cwi-dis/iotsa#182). Buienradar: the
    request line goes, iotsa's outgoing-request line has it; an
    unparseable response is always logged. The clock-hand debug output,
    an if(0) switch before, is -DNEOCLOCK_DEBUG_HANDS. Board files
    refreshed from iotsa.
